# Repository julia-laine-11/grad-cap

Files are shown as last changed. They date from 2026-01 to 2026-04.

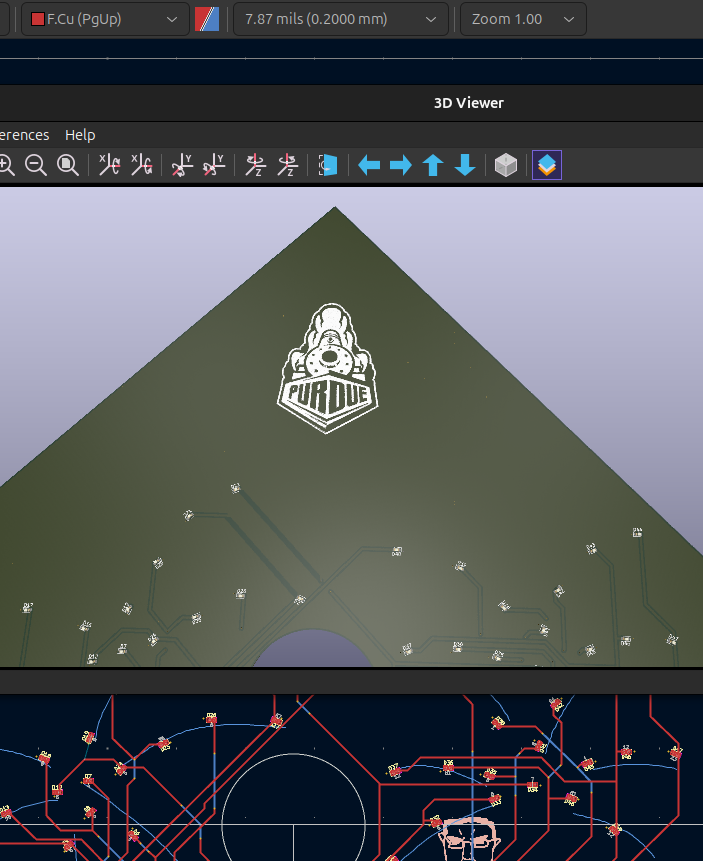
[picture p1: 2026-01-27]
photos/Screenshot from 2026-01-22 17-48-46.png

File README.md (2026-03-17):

# grad-cap
This is a pcb for my grad cap

## Physical:
- the pcb should cover the whole cap
- the pcb should have a space for the little tassle knob in the middle
- the battery should be flat and fit underneath the cap or pcb
- the fireworks should move while the power is on

### LED Sequence:

WhatsApp Video 2026-01-28 at 01 59 47

This was previously 16 frames, but I reduced it to 8 due to the crazy amount of traces needed (and the large amount of time to animate it). I also limited each LED to 2 frames at maximum and reduced the amount of LEDs per firework.
8 frames should be easier to route and less expensive for me to manufacture, lol

### Hardware
- While I originally planned to use a 555 timer, the MIP557 is made to be used in astable mode so I will use that
- It will have a potentiometer instead of a static resistor so that the frame rate can be sped up/lowered



- I did add a footprint for a 555 on the back in case I cannot get this chip to work. I do not have one in person to prototype with.



- the pulse will go into a binary incrementer. At first I was going to use make it myself with 3 flip flops but I couldn't find the chips I needed at the ECE shop so I will just use a binary incrementer that is available.



- the output of the incrementer is then demuxed 3:8



- the demuxed output then goes to OR gates for sections that are active for multiple frames



- and then the rest of the outputs from the mux and the outputs from the OR gates are sent to the MOSFETs


- the LEDs are color coded to what section they are a part of.
- from vote of my friends and family, the stems of the fireworks are white while the blooms are different color.
  


LED resistors:
- input: 3.7v  

  - white: 3.1v  20mA
  
    - 3.7-3.1 = .6/.02 = 30

  - amber: 2v 20mA
  
    - 3.7-2 = 1.7/.02 = 85

  - red: 2v 20mA
  
    - 3.7-2 = 1.7/.02 = 85

  - green: 2.2v 20mA
  
    - 3.7-2.2 = 1.5/.02 = 75
   
30 ohms: 16

80 ohms: 51

#### Prototyping
- I used the 3v output from my STM proto board to power it. The battery will output 3.7v but all of the datasheets say the components can use 3.7v so it's fine.
- I was having difficulty with the output (the gif is short, but yes this is the output)
  
fail1

- This was frustrating since the outputs from the incrementor were displaying properly. (from top to bottom- clock, A0, A1, A2)



- turns out I had the outputs mismatched. I had the input to the mux (A1 and A0) swapped.

success1

- here it is working (going counting in order - 1 is at the top)

- I also needed to check my sizing now that I actually have my cap. I got the initial measurements from a friend who already graduated
  




- Square width: 23.5 cm
- Button diameter: 2.36 cm

    - I will make the overall board a little less than the square width, and the hole for the button a little larger.

- initial kicad measurements from my friend:
  
 


- Rectangle: 24cm, button: 26cm
- rectangle needs to shrink, button is fine :)

- final shape:


#### PCB Images 😀
- I am still working on the silkscreen



- the purdue emblem is on the solder mask layer so it is copper colored
- the handwriting is in silkscreen


- The trace widths for the main branches are 22mils. there are a maximum of ~8 LEDs per branch so I used the digikey trace width calculator and found this width is fine. there are no internal layers so I didnt need to make it any wider.
- power traces are 40 mils.

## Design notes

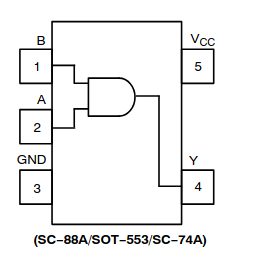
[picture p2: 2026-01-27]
photos/Screenshot from 2026-01-12 10-59-03.png

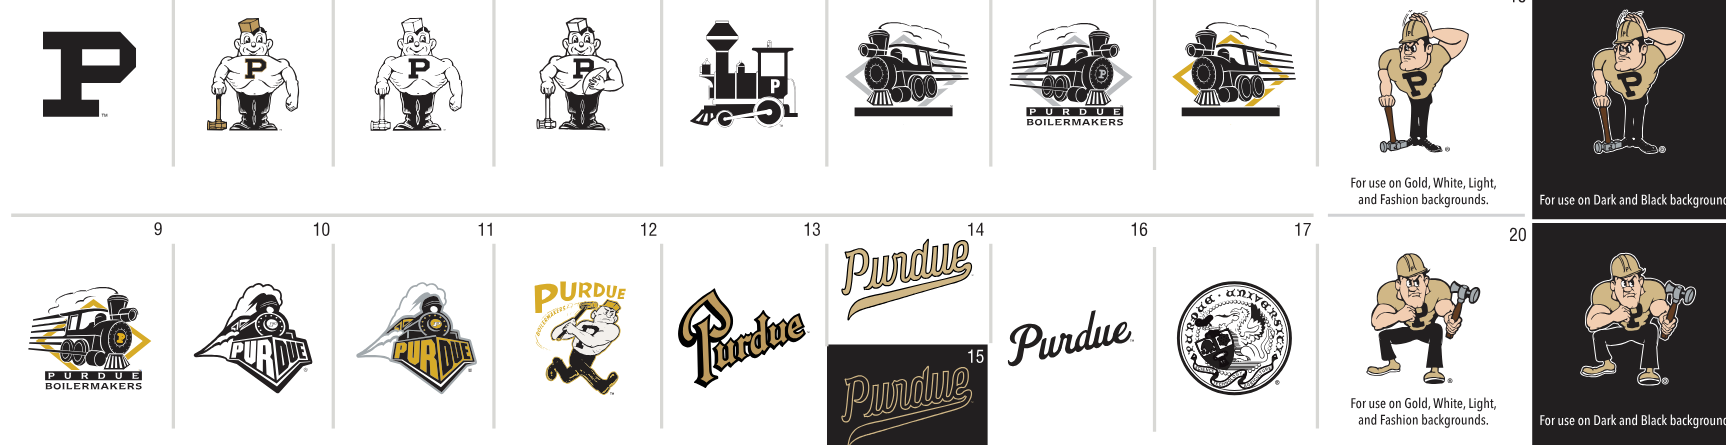
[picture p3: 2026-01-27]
photos/Screenshot from 2026-01-22 17-48-58.png

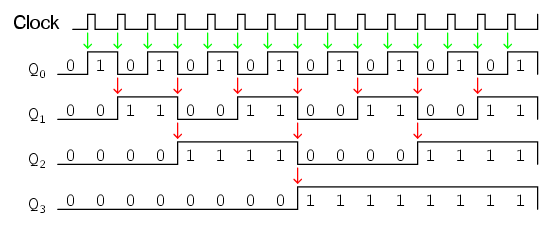
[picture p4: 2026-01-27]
photos/Screenshot from 2026-01-12 11-05-22.png

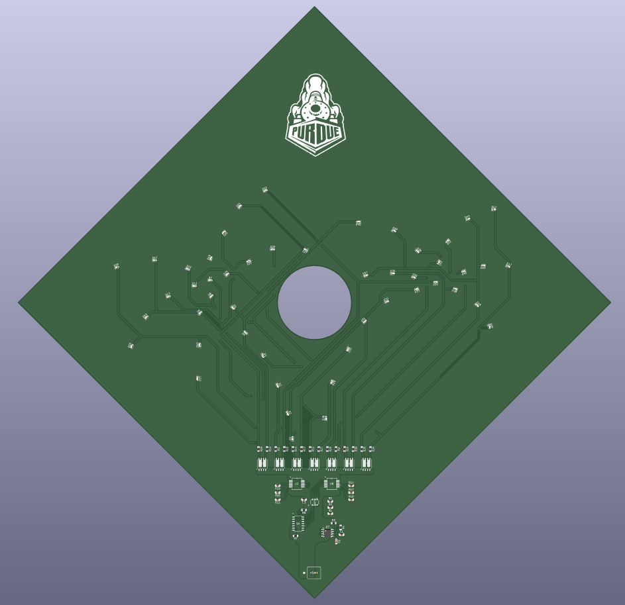
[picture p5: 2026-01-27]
photos/Screenshot from 2026-01-22 17-58-11.png

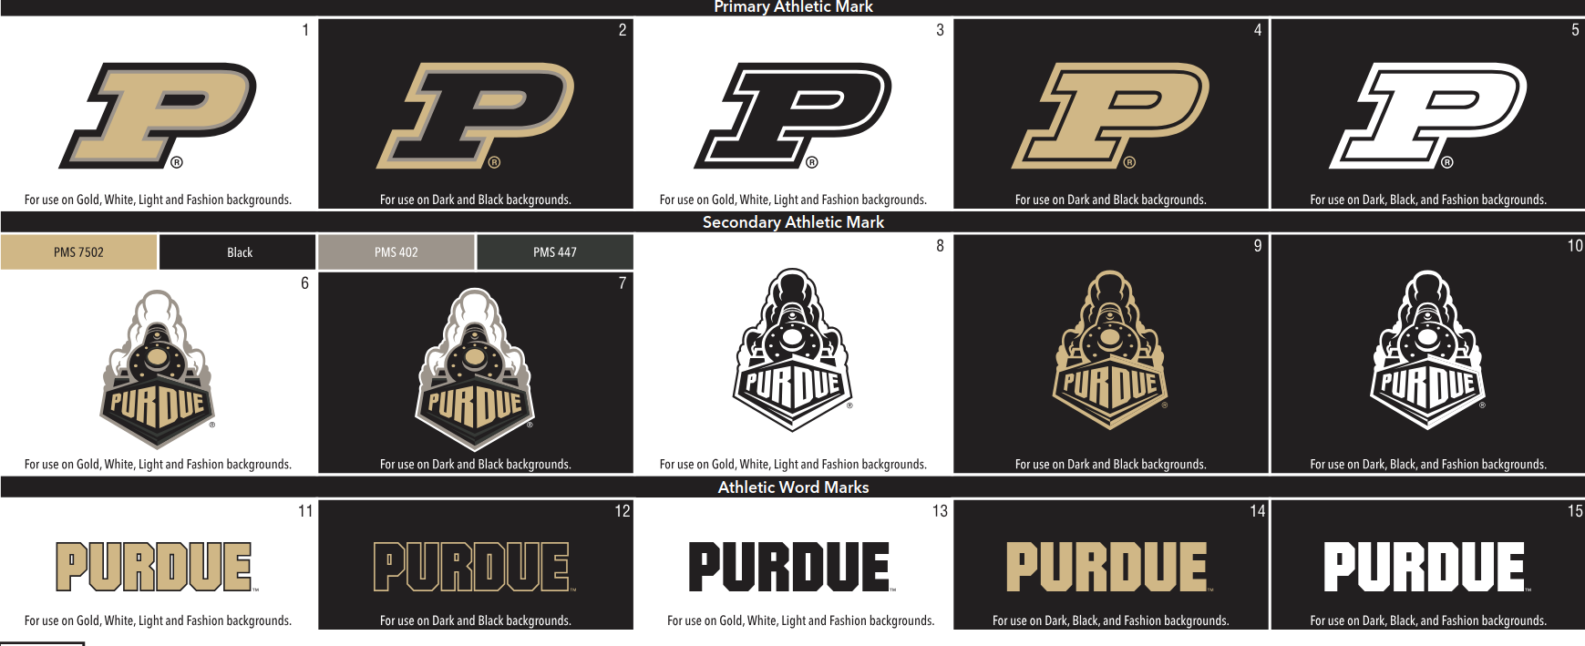
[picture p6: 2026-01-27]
photos/Screenshot from 2026-01-22 17-49-37.png

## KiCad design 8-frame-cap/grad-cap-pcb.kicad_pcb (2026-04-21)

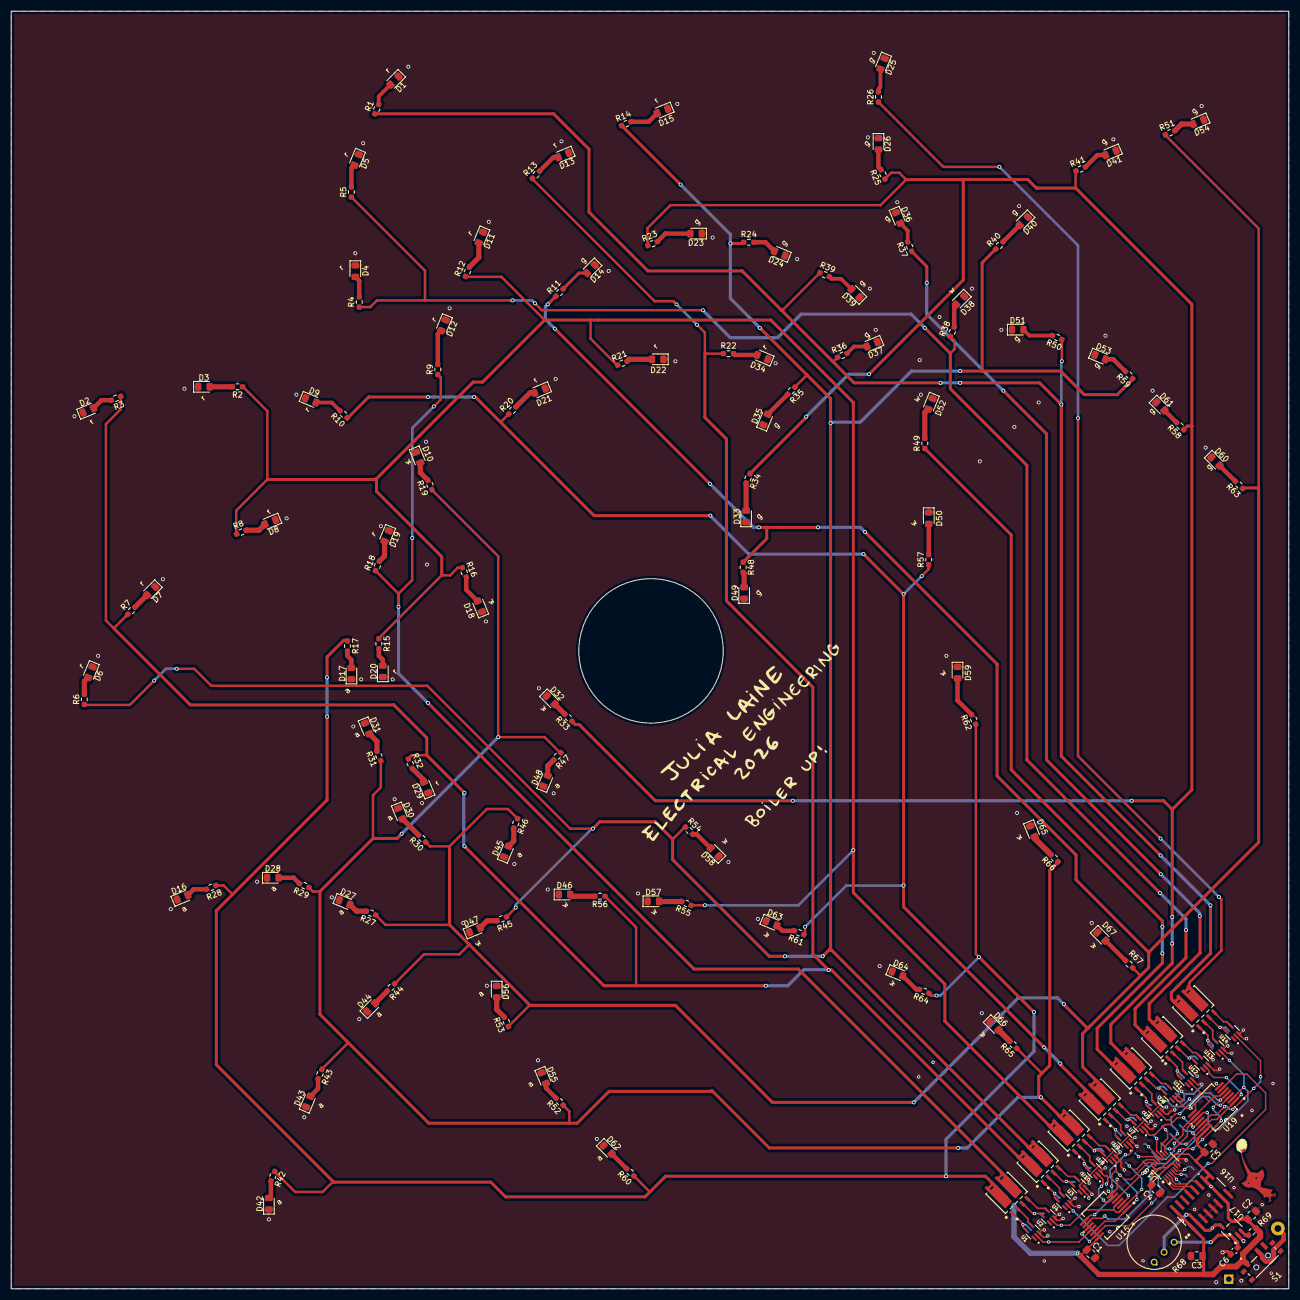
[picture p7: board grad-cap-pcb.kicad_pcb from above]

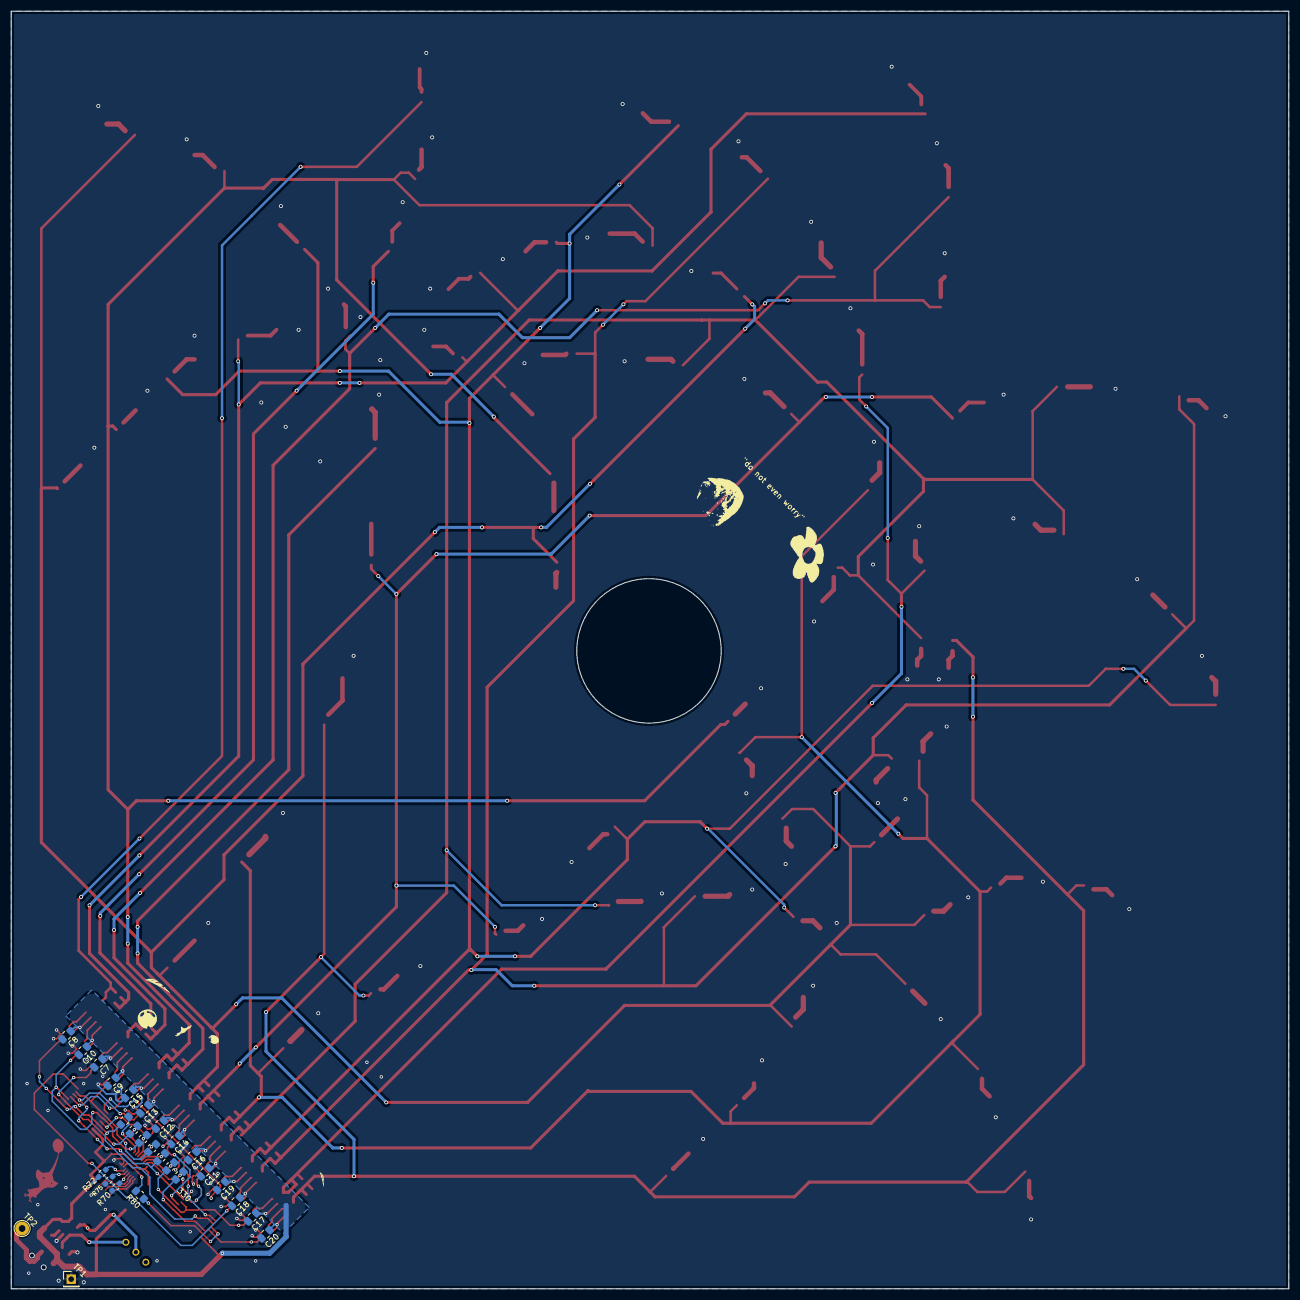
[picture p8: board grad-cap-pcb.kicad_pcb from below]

Board: 2 copper layers, 230.0 x 230.0 mm, 196 parts (27 on the bottom side), 131 nets.

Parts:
C1, C2, C3, C4, C5, C7, C8, C9, C10, C11, C12, C13, C14, C15, C16, C17, C18, C19, C20: .1uf; C_0805_2012Metric_Pad1.18x1.45mm_HandSolder
C6: .1uF; C_0603_1608Metric_Pad1.08x0.95mm_HandSolder
D1, D2, D3, D4, D5, D6, D7, D8, D9, D10, D11, D12, D13, D14, D15, D16, D17, D18, D19, D20, D21, D22, D23, D24, D25, D26, D27, D28, D29, D30, D31, D32, D33, D34, D35, D36, D37, D38, D39, D40, D41, D42, D43, D44, D45, D46, D47, D48, D49, D50, D51, D52, D53, D54, D55, D56, D57, D58, D59, D60, D61, D62, D63, D64, D65, D66, D67: LED_0805_2012Metric_Pad1.15x1.40mm_HandSolder
R1, R2, R3, R4, R5, R6, R7, R8, R9, R10, R11, R12, R13, R14, R15, R16, R17, R18, R19, R20, R21, R22, R23, R24, R25, R26, R27, R28, R29, R30, R31, R32, R33, R34, R35, R36, R37, R38, R39, R40, R41, R42, R43, R44, R45, R46, R47, R48, R49, R50, R51, R52, R53, R54, R55, R56, R57, R58, R59, R60, R61, R62, R63, R64, R65, R66, R67: R_Small_US; R_0603_1608Metric_Pad0.98x0.95mm_HandSolder
R68: 91AR1MEGLF; 1M-potentiometer
R69: 1M; R_0603_1608Metric_Pad0.98x0.95mm_HandSolder
R70, R72, R75: 10k; R_0603_1608Metric_Pad0.98x0.95mm_HandSolder
R71, R73, R74, R76, R77, R78, R79, R80: 300; R_0805_2012Metric_Pad1.20x1.40mm_HandSolder
S1: ON/OFF; spdt-switch
T1, T2, T3, T4, T5, T6, T7: PHPT610035PKX; PHPT610035PKX_TRANS-2PNP-100V-3A
TP1: TestPoint; PinHeader_1x01_P2.54mm_Vertical
TP2: TestPoint; TestPoint_THTPad_D2.5mm_Drill1.2mm
U1, U2, U3, U4, U5, U6, U7, U8, U9, U10, U11, U12, U13, U14: SN74LVC1G14DCKR; SN74LVC-INVERTER
U15, U19: SN74AHCT32DBR; SN74AHCT32DBR_2-INPUT-QUAD-OR
U16: SN74HC163DR; binary counter - 74hc163
U17: MIC1557YM5-TR; MIC1557
U18: SN74HCS238DYYR; SN74HCS238DYYR-3-8-MUX

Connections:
0: R78.2, U15.1 (1A), U15.12 (4A)
1: R73.2, U2.2 (A), U15.2 (1B), U15.4 (2A)
1or2: R10.1, R20.1, R57.1, R61.1, T5.8 (COLLECTOR)
2: R74.2, U5.2 (A), U15.5 (2B), U19.4 (2A)
2or3: R2.1, R8.1, R12.1, R15.1, R16.1, R21.1, R55.1, T3.8 (COLLECTOR)
3: R79.2, U11.2 (A), U19.5 (2B), U19.9 (3A)
3or4: R3.1, R7.1, R13.1, R22.1, R32.1, R56.1, T2.8 (COLLECTOR)
4: R77.2, U13.2 (A), U19.2 (1B), U19.10 (3B)
4or5: R6.1, R14.1, R24.1, R35.1, R40.1, R45.1, R54.1, R59.1, T2.6 (COLLECTOR)
5: R76.2, U12.2 (A), U19.1 (1A), U19.13 (4B)
5or6: R23.1, R25.1, R33.1, R34.1, R41.1, R58.1, T4.6 (COLLECTOR)
6: R71.2, U14.2 (A), U15.9 (3A), U19.12 (4A)
6or7: R11.1, R27.1, R30.1, R44.1, R46.1, R48.1, R51.1, R53.1, R63.1, R67.1, T5.6 (COLLECTOR)
7: R80.1, U15.10 (3B), U15.13 (4B)
7or8: R19.1, R29.1, R31.1, R43.1, R47.1, R52.1, R65.1, R66.1, T3.6 (COLLECTOR)
8or1: R17.1, R28.1, R42.1, R60.1, R62.1, R64.1, T1.8 (COLLECTOR)
557-PULSE: R68.2, U16.2 (CLK), U17.5 (OUT)
+3.3V: C1.1, C2.1, C3.1, C4.1, C5.1, C7.1, C8.1, C9.1, C10.1, C11.1, C12.1, C13.1, C14.1, C15.1, C16.1, C17.1, C18.1, C19.1, C20.1, R69.1, R72.2, S1.1, T1.1 (EMITTER), T1.3 (EMITTER), T2.1 (EMITTER), T2.3 (EMITTER), T3.1 (EMITTER), T3.3 (EMITTER), T4.1 (EMITTER), T4.3 (EMITTER), T5.1 (EMITTER), T5.3 (EMITTER), T6.1 (EMITTER), T6.3 (EMITTER), T7.1 (EMITTER), T7.3 (EMITTER), U1.5 (VCC), U2.5 (VCC), U3.5 (VCC), U4.5 (VCC), U5.5 (VCC), U6.5 (VCC), U7.5 (VCC), U8.5 (VCC), U9.5 (VCC), U10.5 (VCC), U11.5 (VCC), U12.5 (VCC), U13.5 (VCC), U14.5 (VCC), U15.14 (VCC), U16.1 (*CLR), U16.7 (ENP), U16.9 (*LOAD), U16.10 (ENT), U16.16 (VCC), U17.4 (VS), U18.16 (VCC), U19.14 (VCC)
+BATT: S1.2, TP2.1
/pd-mux-g0: R70.1, U18.4 (*G0)
/pd-mux-g1: R75.1, U18.5 (*G1)
/pu-mux-g2: R72.1, U18.6 (G2)
CLOCK1: U16.13 (QB), U18.1 (A0)
CLOCK2: U16.12 (QC), U18.2 (A1)
CLOCK3: U16.11 (QD), U18.3 (A2)
GND: C1.2, C2.2, C3.2, C4.2, C5.2, C6.2, C7.2, C8.2, C9.2, C10.2, C11.2, C12.2, C13.2, C14.2, C15.2, C16.2, C17.2, C18.2, C19.2, C20.2, D1.1 (K), D2.1 (K), D3.1 (K), D4.1 (K), D5.1 (K), D6.1 (K), D7.1 (K), D8.1 (K), D9.1 (K), D10.1 (K), D11.1 (K), D12.1 (K), D13.1 (K), D14.1 (K), D15.1 (K), D16.1 (K), D17.1 (K), D18.1 (K), D19.1 (K), D20.1 (K), D21.1 (K), D22.1 (K), D23.1 (K), D24.1 (K), D25.1 (K), D26.1 (K), D27.1 (K), D28.1 (K), D29.1 (K), D30.1 (K), D31.1 (K), D32.1 (K), D33.1 (K), D34.1 (K), D35.1 (K), D36.1 (K), D37.1 (K), D38.1 (K), D39.1 (K), D40.1 (K), D41.1 (K), D42.1 (K), D43.1 (K), D44.1 (K), D45.1 (K), D46.1 (K), D47.1 (K), D48.1 (K), D49.1 (K), D50.1 (K), D51.1 (K), D52.1 (K), D53.1 (K), D54.1 (K), D55.1 (K), D56.1 (K), D57.1 (K), D58.1 (K), D59.1 (K), D60.1 (K), D61.1 (K), D62.1 (K), D63.1 (K), D64.1 (K), D65.1 (K), D66.1 (K), D67.1 (K), R70.2, R75.2, S1.3, TP1.1, U1.3 (GND), U2.3 (GND), U3.3 (GND), U4.3 (GND), U5.3 (GND), U6.3 (GND), U7.3 (GND), U8.3 (GND), U9.3 (GND), U10.3 (GND), U11.3 (GND), U12.3 (GND), U13.3 (GND), U14.3 (GND), U15.7 (GND), U16.3 (A), U16.4 (B), U16.5 (C), U16.6 (D), U16.8 (GND), U17.2 (GND), U18.8 (GND), U19.7 (GND)
unnamed: D66.2 (A), R65.2
unnamed: D64.2 (A), R64.2
unnamed: D63.2 (A), R61.2
unnamed: D57.2 (A), R55.2
unnamed: D46.2 (A), R56.2
unnamed: D47.2 (A), R45.2
unnamed: D56.2 (A), R53.2
unnamed: D55.2 (A), R52.2
unnamed: D62.2 (A), R60.2
unnamed: D44.2 (A), R44.2
unnamed: D43.2 (A), R43.2
unnamed: D42.2 (A), R42.2
unnamed: D27.2 (A), R27.2
unnamed: D28.2 (A), R29.2
unnamed: D16.2 (A), R28.2
unnamed: D30.2 (A), R30.2
unnamed: D31.2 (A), R31.2
unnamed: D17.2 (A), R17.2
unnamed: D45.2 (A), R46.2
unnamed: D48.2 (A), R47.2
unnamed: D58.2 (A), R54.2
unnamed: D32.2 (A), R33.2
unnamed: D18.2 (A), R16.2
unnamed: D10.2 (A), R19.2
unnamed: D19.2 (A), R18.2
unnamed: D20.2 (A), R15.2
unnamed: D29.2 (A), R32.2
unnamed: D8.2 (A), R8.2
unnamed: D7.2 (A), R7.2
unnamed: D6.2 (A), R6.2
unnamed: D9.2 (A), R10.2
unnamed: D3.2 (A), R2.2
unnamed: D2.2 (A), R3.2
unnamed: D4.2 (A), R4.2
unnamed: D5.2 (A), R5.2
unnamed: D1.2 (A), R1.2
unnamed: D12.2 (A), R9.2
unnamed: D11.2 (A), R12.2
unnamed: D13.2 (A), R13.2
unnamed: D15.2 (A), R14.2
unnamed: D21.2 (A), R20.2
unnamed: D22.2 (A), R21.2
unnamed: D34.2 (A), R22.2
unnamed: D67.2 (A), R67.2
unnamed: D65.2 (A), R66.2
unnamed: D59.2 (A), R62.2
unnamed: D50.2 (A), R57.2
unnamed: D52.2 (A), R49.2
unnamed: D38.2 (A), R38.2
unnamed: D37.2 (A), R36.2
unnamed: D35.2 (A), R35.2
unnamed: D33.2 (A), R34.2
unnamed: D49.2 (A), R48.2
unnamed: D39.2 (A), R39.2
unnamed: D24.2 (A), R24.2
unnamed: D23.2 (A), R23.2
unnamed: D14.2 (A), R11.2
unnamed: D36.2 (A), R37.2
unnamed: D26.2 (A), R25.2
unnamed: D25.2 (A), R26.2
unnamed: D40.2 (A), R40.2
unnamed: D41.2 (A), R41.2
unnamed: D54.2 (A), R51.2
unnamed: D51.2 (A), R50.2
unnamed: D53.2 (A), R59.2
unnamed: D61.2 (A), R58.2
unnamed: D60.2 (A), R63.2
unnamed: R69.2, U17.3 (CS)
unnamed: C6.1, R68.3, U17.1 (T/T)
unnamed: R78.1, U18.15 (Y0)
unnamed: R73.1, U18.14 (Y1)
unnamed: R74.1, U18.13 (Y2)
unnamed: R79.1, U18.12 (Y3)
unnamed: R77.1, U18.11 (Y4)
unnamed: R76.1, U18.10 (Y5)
unnamed: R71.1, U18.9 (Y6)
unnamed: R80.2, U18.7 (Y7)
unnamed: T1.2 (BASE), U1.4 (Y)
unnamed: T3.2 (BASE), U10.4 (Y)
unnamed: T4.2 (BASE), U5.4 (Y)
unnamed: T7.2 (BASE), U13.4 (Y)
unnamed: T1.4 (BASE), U2.4 (Y)
unnamed: T3.4 (BASE), U8.4 (Y)
unnamed: T4.4 (BASE), U6.4 (Y)
unnamed: T7.4 (BASE), U14.4 (Y)
unnamed: T2.2 (BASE), U4.4 (Y)
unnamed: T5.2 (BASE), U9.4 (Y)
unnamed: T6.2 (BASE), U11.4 (Y)
unnamed: T2.4 (BASE), U3.4 (Y)
unnamed: T5.4 (BASE), U7.4 (Y)
unnamed: T6.4 (BASE), U12.4 (Y)
f1or2: U9.2 (A), U15.3 (1Y)
f1or8: U1.2 (A), U15.11 (4Y)
f2or3: U10.2 (A), U15.6 (2Y)
f3or4: U4.2 (A), U19.6 (2Y)
f4or5: U3.2 (A), U19.8 (3Y)
f5or6: U6.2 (A), U19.3 (1Y)
f6or7: U7.2 (A), U19.11 (4Y)
f7or8: U8.2 (A), U15.8 (3Y)
frame1: R9.1, R18.1, T1.6 (COLLECTOR)
frame2: R49.1, T4.8 (COLLECTOR)
frame3: R4.1, R5.1, R38.1, T6.8 (COLLECTOR)
frame4: R1.1, R36.1, R39.1, R50.1, T7.8 (COLLECTOR)
frame5: R37.1, T6.6 (COLLECTOR)
frame6: R26.1, T7.6 (COLLECTOR)

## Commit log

2026-01-11 laid out leds
    [adder.kicad_sch, demux.kicad_sch, grad-cap-pcb.kicad_pcb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]
2026-01-12 added led sequence chart
2026-01-13 addd more
    switched from npn to pnp to make the LEDs connect to the ground plane - easier routing.
    added labels and or gates so the mosfets wouldnt trigger each other
    [demux.kicad_sch, grad-cap-pcb.kicad_pcb, leds+mosfets.kicad_sch]
2026-01-14 added many things
    added: mux
    counter
    signal gen - still needs r1 and r2 values
    power management
    kicad symbol library - footprints not assigned
    [1X02JST.STEP, Book 9(Sheet1)(1).csv, CD4072BM96_4-INPUT-OR.stp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]
2026-01-14 edited layout
    [CD74HC154M96_4:16-MUX.stp, grad-cap-pcb.kicad_pcb, grad-cap-pcb.kicad_sch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]
2026-01-21 routed traces, added resistors
    [grad-cap-pcb.kicad_pcb, grad-cap-pcb.kicad_sch, leds+mosfets.kicad_sch]
2026-01-21 screw it were making it 8 frames, 16 is too mcuh
    [grad-cap-pcb.kicad_pcb, grad-cap-pcb.kicad_sch, leds+mosfets.kicad_sch]
2026-01-27 added 8 frame option + updated power supply
    - i was having trouble with the 4 layer since it would be expensive to make and it also had a loottttt of traces.
    - added resistor per led because im not sure what i was on when i decided i only needed 1 resistor per frame.
    - changed the tails to white instead of the same color by popular vote of my friends
    - removed 3v7 -> 2v1 converter
    [grad-cap-pcb.kicad_pcb, grad-cap-pcb.kicad_sch, leds+mosfets.kicad_sch]
2026-01-28 update readme due to large changes
    Reduced LED frames from 16 to 8 for easier routing and manufacturing. Updated hardware details and pulse generation options.
2026-01-28 Revise LED colors and frame count in README
    Updated LED specifications and reduced frame count for fireworks.
2026-02-08 routed traces, reorganized, renamed
    [grad-cap-pcb.kicad_pcb, grad-cap-pcb.kicad_sch, leds+mosfets.kicad_sch]
2026-02-10 reorganized
    horizontal -> vertical pin headers
    traces added
    moved components
    switched clocks crystal-> si
    [grad-cap-pcb.kicad_pcb]
2026-02-12 updated pcb
    error checking
    90* angles removal
    schematic relinking
    reorganizing schematic
    fixed footprints for PHPT6 (mosfets, they didnt like the pads and the body being "different" pours or something)
    silkscreen reorg
    [grad-cap-pcb.kicad_pcb, grad-cap-pcb.kicad_sch, leds+mosfets.kicad_sch]
2026-02-12 removed old files
    i am no longer using the 16 frame cap and the initial try of the 8 frame cap was too boring. removing these files for clarity
    [1X02JST.STEP, CD4072BM96_4-INPUT-OR.stp, CD4075BM96-3IN-TRIO-OR.stp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]
2026-02-13 updated pcb
    shrunk edge cuts
    moved led matrix header (again)
    added 3d file links
    added mounting holes
    added 3 on board buttons
    fixed unused pin header connections
    discovered polygon filled area default chamfer (i will be using this always now)
    updated bom with new caps
    added status LED for usbc power in
    [grad-cap-pcb.kicad_pcb, grad-cap-pcb.kicad_sch, leds+mosfets.kicad_sch]
2026-02-13 updated silkscreen
    added custom designs
    - put them to the side
    lowkey cant decide what to do with them, or if i put them at all
    [grad-cap-pcb.kicad_pcb]
2026-02-23 Revise hardware details and add PCB images
    Updated hardware section with new components and configurations. Added PCB images and silkscreen options.
2026-03-09 update readme
    - prototyping
    - pcb update
    - schematic update
2026-03-09 updated from prototyping
    - jk ff -> incrementer
    - shrink to be cap size
    - rename labels to match layout
    [grad-cap-pcb.kicad_pcb, grad-cap-pcb.kicad_sch, leds+mosfets.kicad_sch]
2026-03-18 updated pcb
    added labels for each diode
    changed silkscreen to be handwriting
    [grad-cap-pcb.kicad_pcb, grad-cap-pcb.kicad_sch, leds+mosfets.kicad_sch]
2026-03-30 final push
    [grad-cap-pcb-B_Cu.gbr, grad-cap-pcb-B_Mask.gbr, grad-cap-pcb-B_Paste.gbr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]
2026-04-09 final push
    inverters for pmos
    resistors for mux
    silkscreen looking fire as hell honestly
    [grad-cap-pcb-B_Cu.gbr, grad-cap-pcb-B_Mask.gbr, grad-cap-pcb-B_Paste.gbr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]
